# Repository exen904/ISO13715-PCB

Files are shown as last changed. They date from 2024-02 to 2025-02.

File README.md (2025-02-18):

# ISO13715 Macropad

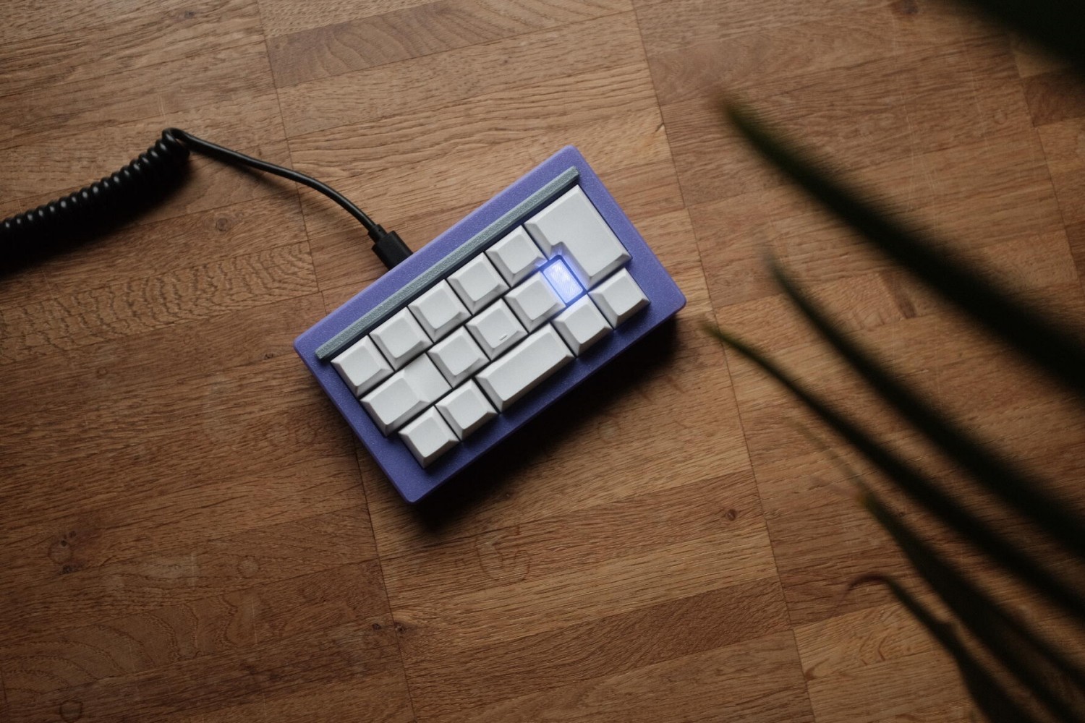
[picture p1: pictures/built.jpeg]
built macropad


Name derives from DIN ISO 13715 ```Kanten mit unbestimmter Gestalt```. Depending on the layout you choose for the bottom row 13/15 keys, 7 where the regular Alpha cluster would be and ISO should be obvious. 

Huge shoutout to PCBway, who sponsored the run of the matte black PCB I used in the build guide. No strings attached here, if you want a matte black PCB, thats the way to go.

## PCB
You can find the Gerber files for ordering your own PCB in the `PCB\production` folder. For service I can absolutely recommend PCBway, who as mentioned above, sponsored my prototype run. Service was great and they deliver quality work, so I can really recommend them.

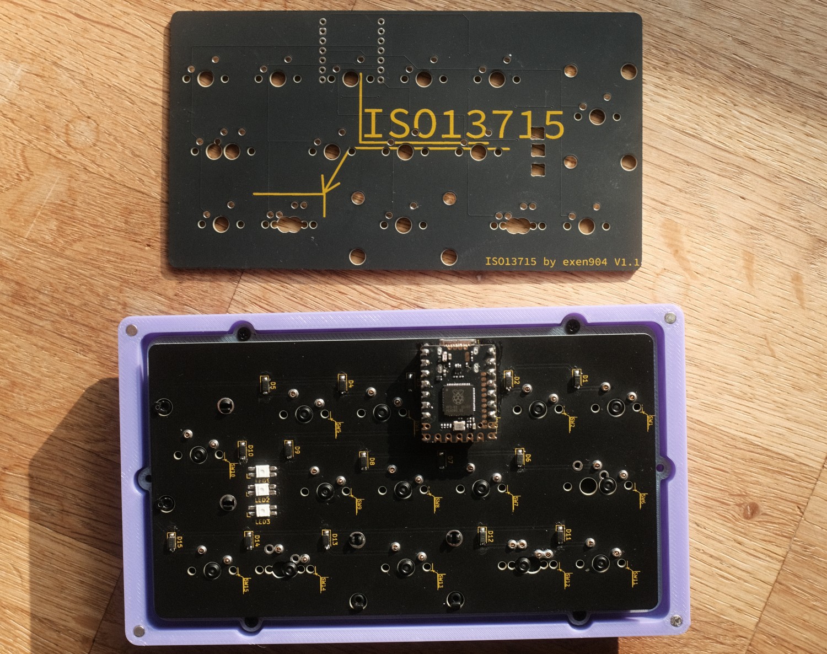
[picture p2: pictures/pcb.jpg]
PCBway PCB


## BOM
- 15x SOD123 Diodes
- 3x SK-6812 MINI-E
- 2x 2U PCB mounted Stabilizers
- 1x MCU of your choice
- 8x 3x3mm magnets for the case
- 4-6x M2x3 heat inserts (4 should be more than fine)
- 4-6x M2x4 screws

For the MCU you have two options. Either XIAO RP2040, or Waveshare RP2040 Zero/0xCB Gemini. Both fit and work, however the pinout is mirrored on either option. I originally designed the PCB for the Xiao, with the MCU facing towards you (not like most split builds with face down MCUs). However, my Proto is built with a RP2040 zero, which has to be flipped on its face. I recommend using IC sockets for the MCU. 

## Case
The current case only supports the HHKB bottom row with 2x 1U keys, the version with the larger blockers is still on my todo. If you cant wait though, feel free to edit the STEP files to your needs. For the diffusor, I chose transparent PETG and for a more unified look, changed the last layer to white. The mounting system of the case itself is inspired from the awesome cases from Bubbleology and uses the same magnets.

For printing, I recommend 0.2mm layer height, anything around 10% infill. How tight the plate works for you also depends on the swichtes you choose, if its too loose you can play around with the XY Hole compensation in your slicer.

## Firmware
I started with a very basic KMK firmware based of POG to test everything, which is still included here in the Repo. However, now I also finished the QMK-VIAL port for the board. I only tested this on a 0xCB Gemini, not on a Xiao RP2040. As the Xiao exposes different pins, those need to be changed before compiling the firmware. I currently dont have one on hand to test, so Im not going to provide untested firmware files. Please adjust here for yourself.

If you are using a Helios/RP2040 Zero, you can use the provided `iso13715_vial_gemini.uf2` in the `Firmware` folder. The VIAL firmware also has bootmagic enabled, so to get into bootloader mode, you just need to hold down the imaginary `ESC` key on the board.

### KLE layout options

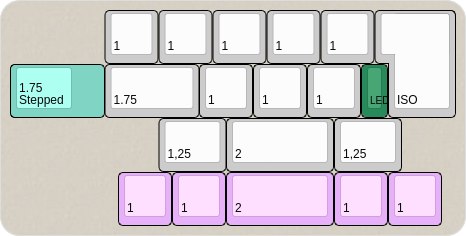
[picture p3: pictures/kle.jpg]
Screenshot of KLE


## Build Guide
[You can find the build guide for the PCB here](https://github.com/exen904/ISO13715-PCB/blob/main/build_guide.md)

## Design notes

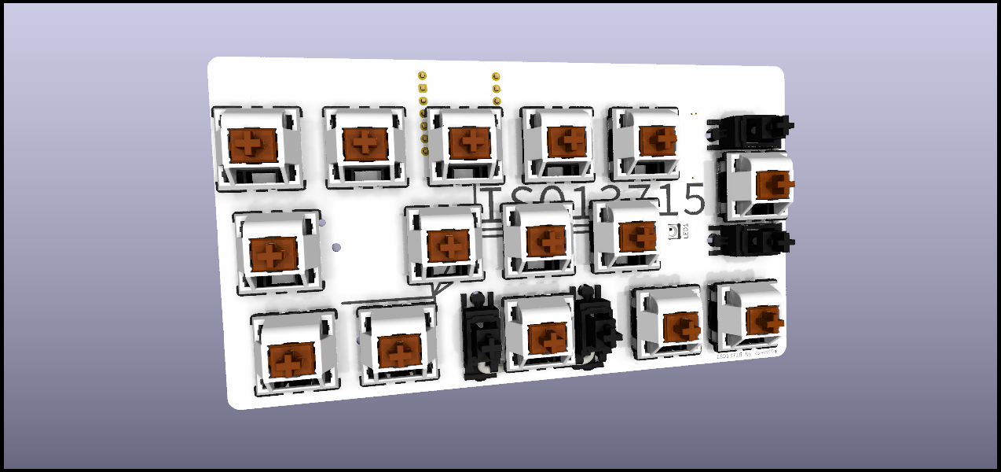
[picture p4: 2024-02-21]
pictures/ISO13715.png

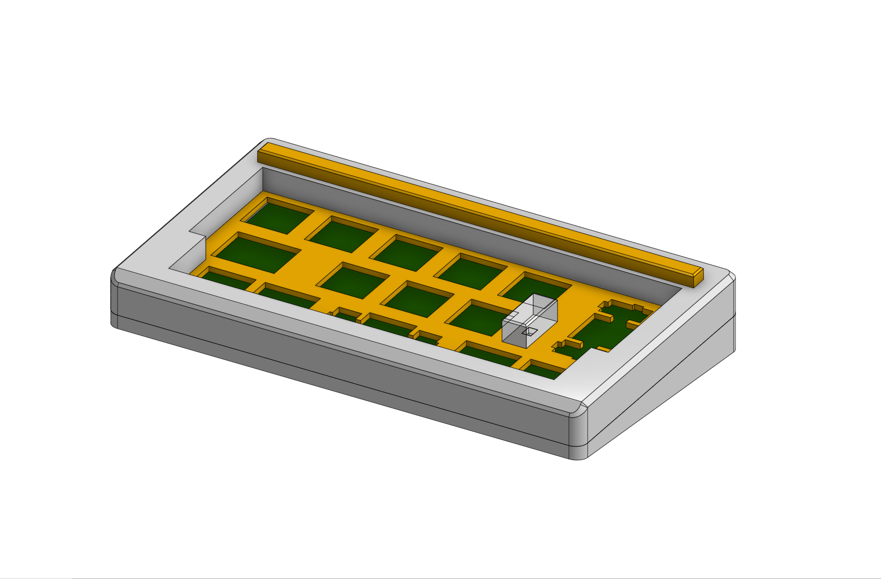
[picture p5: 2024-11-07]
Case/iso13715.png

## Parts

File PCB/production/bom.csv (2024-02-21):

Designator | Footprint | Quantity | Value | LCSC Part #
D1, D10, D11, D12, D13, D14, D15, D2, D3, D4, D5, D6, D7, D8, D9 | D_SOD-123 | 15 | 1N4148W
LED1, LED2, LED3 | LED_6028R | 3 | SK6812MINI-E
SW1, SW6 | SW_MX_1u | 2 | ~
SW10, SW11, SW12, SW13, SW14, SW15, SW2, SW3, SW4, SW5, SW7, SW8, SW9 | SW_MX_1u_3D | 13 | ~
SW17, SW18 | SW_MX_1.25u | 2 | ~
SW20 | SW_MX_1.75u_STP_1.25 | 1 | ~

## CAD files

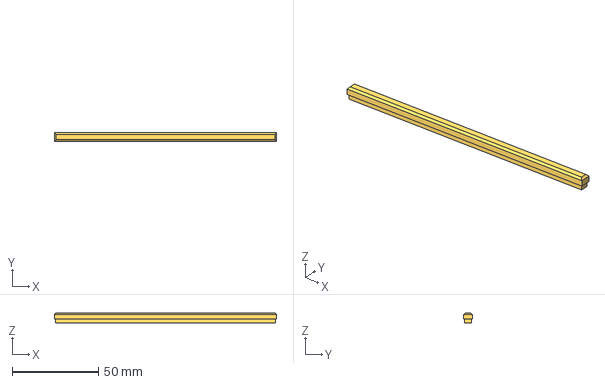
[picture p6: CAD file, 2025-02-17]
Case/STEP/Case - Rail.step
129.0 x 5.03 x 6.10 mm

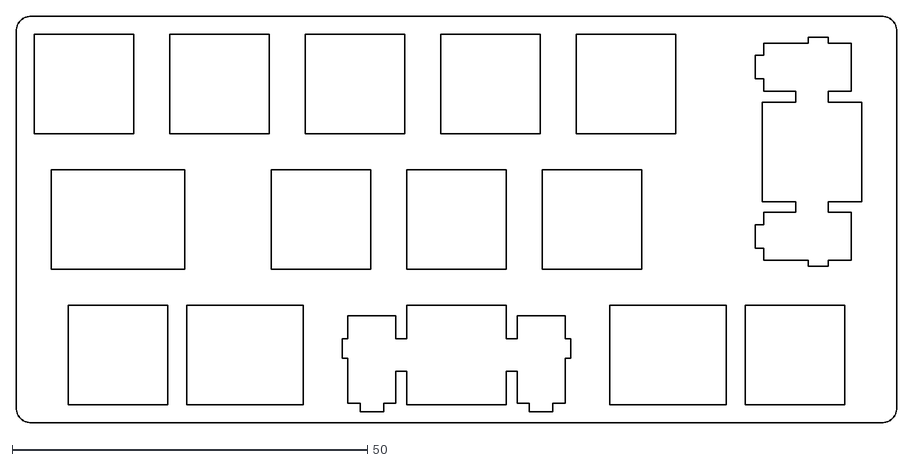
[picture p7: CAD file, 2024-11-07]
Plate/plate_swillkb.dxf
123.8 x 57.2

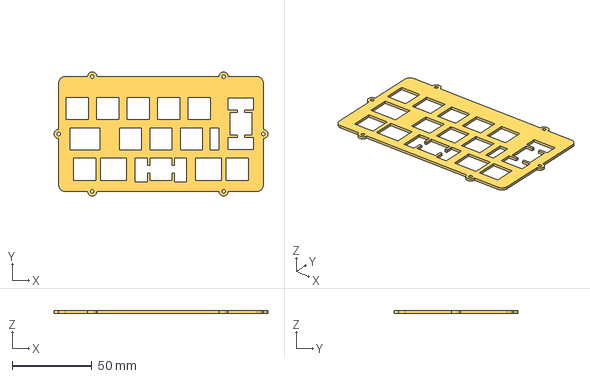
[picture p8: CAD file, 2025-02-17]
Case/STEP/Case - Plate.step
133.8 x 77.6 x 1.60 mm

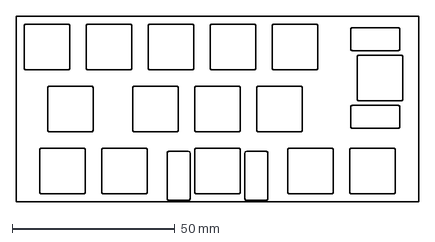
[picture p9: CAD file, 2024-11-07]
Plate/plate-2024-01-22T20_08_51.751Z.dxf
123.8 x 57.1 mm

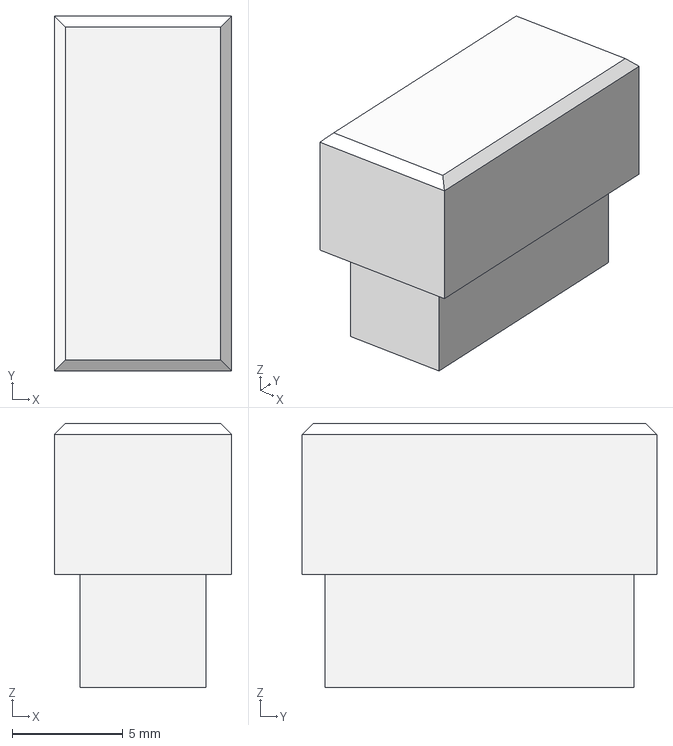
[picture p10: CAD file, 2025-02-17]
Case/STEP/Case - Diffusor.step
8.00 x 16.0 x 11.9 mm

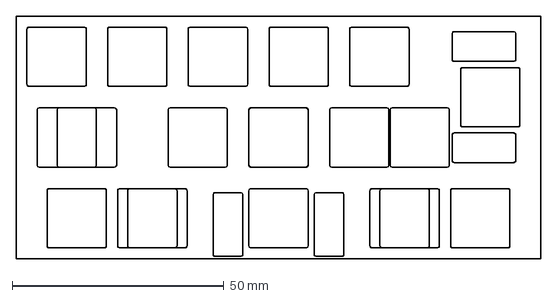
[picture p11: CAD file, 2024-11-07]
Plate/plate-2024-01-23T20_27_40.417Z.dxf
123.8 x 57.1 mm

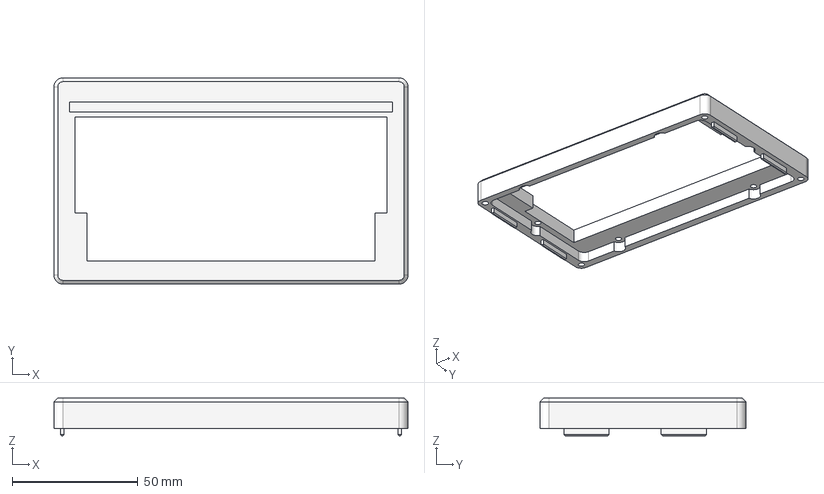
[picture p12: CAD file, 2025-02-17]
Case/STEP/Case - Topcase.step
140.5 x 81.8 x 15.0 mm

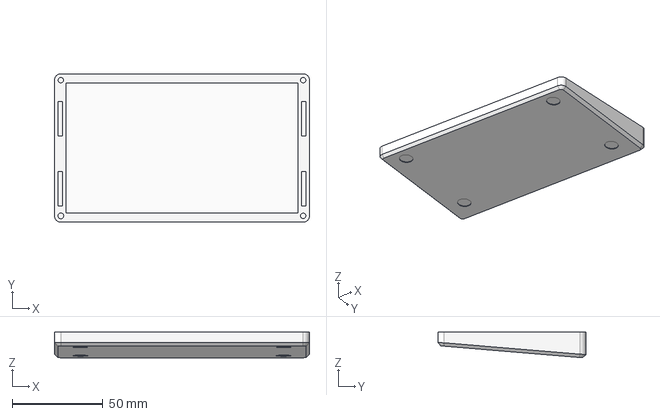
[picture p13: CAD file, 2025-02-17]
Case/STEP/Case - Bottom Case.step
140.5 x 81.8 x 14.1 mm

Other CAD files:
Case/STL/Case - Bottom Case.stl
Case/STL/Case - Diffusor.stl
Case/STL/Case - Plate.stl
Case/STL/Case - Rail.stl
Case/STL/Case - Topcase.stl

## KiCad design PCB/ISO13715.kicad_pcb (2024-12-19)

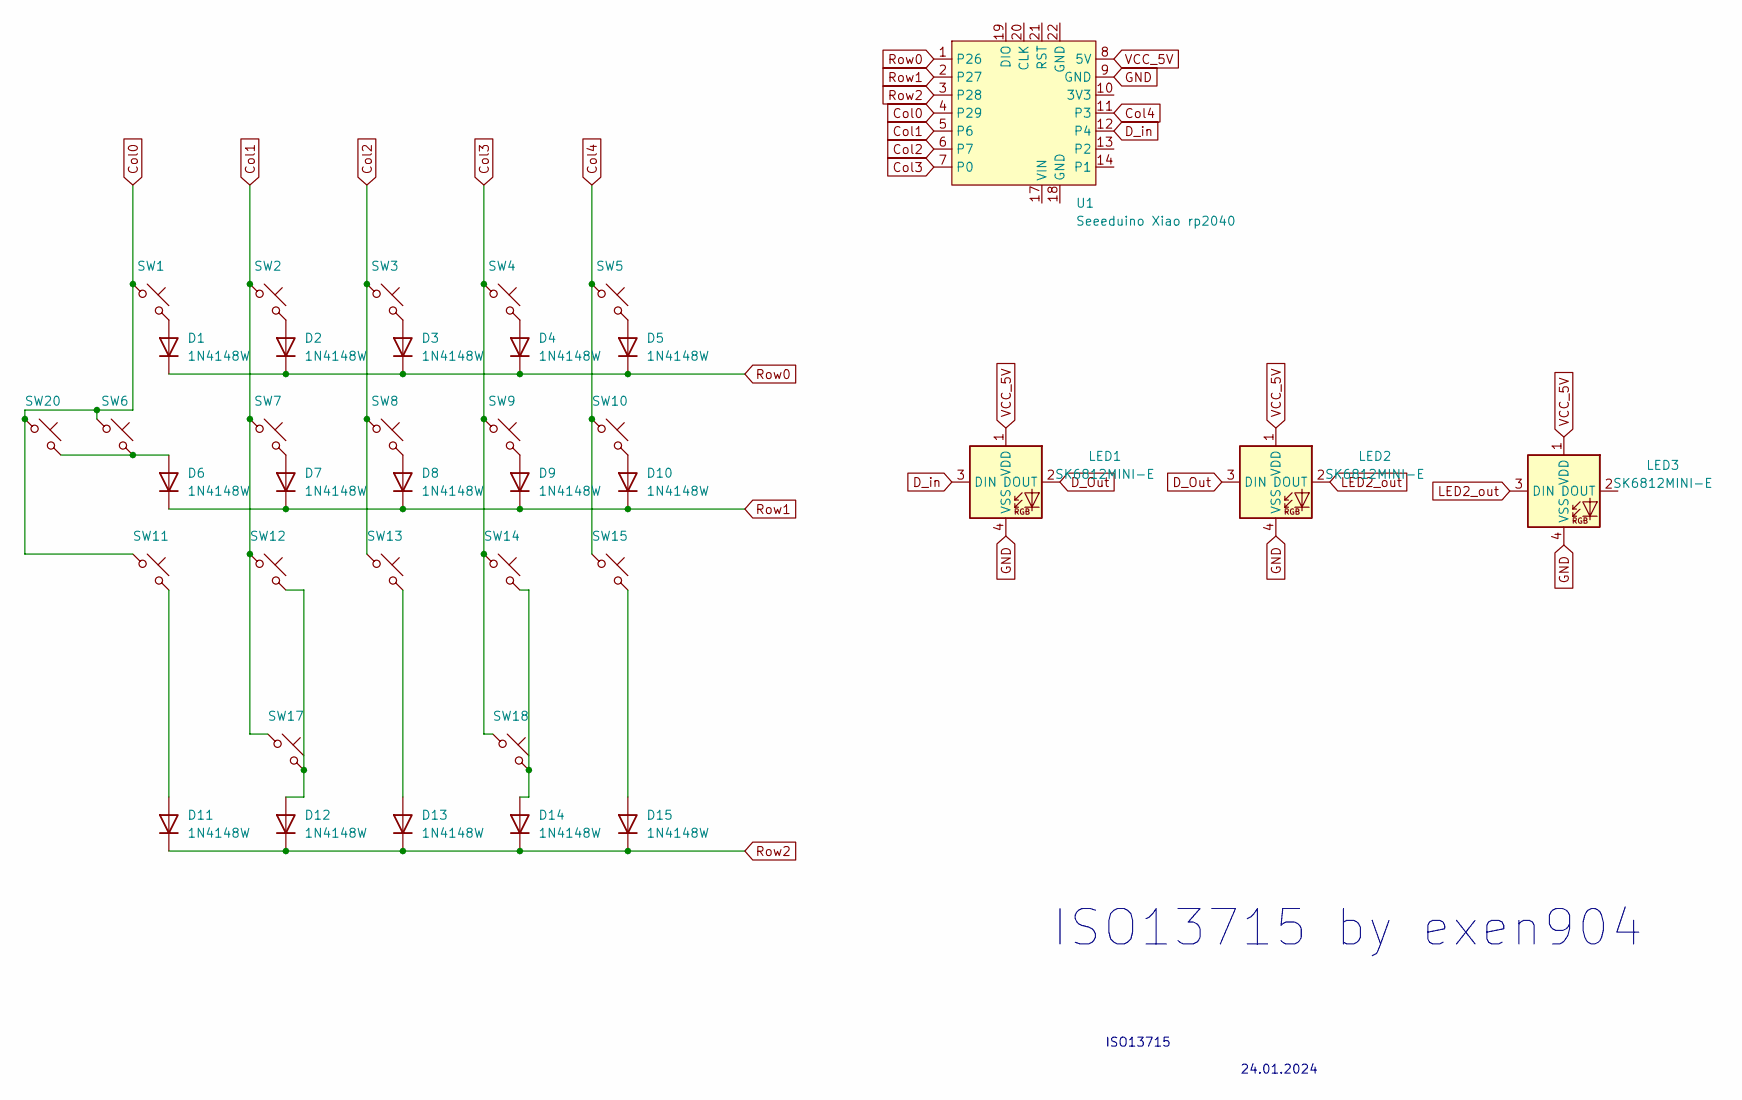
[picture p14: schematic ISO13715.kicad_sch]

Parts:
D1, D2, D3, D4, D5, D6, D7, D8, D9, D10, D11, D12, D13, D14, D15: 1N4148W; D_SOD-123
LED1, LED2, LED3: SK6812MINI-E; LED_6028R
SW1, SW2, SW3, SW4, SW5, SW7, SW8, SW9, SW10, SW11, SW12, SW13, SW14, SW15: SW_MX_1u
SW6, SW20: SW_MX_1.75u
SW17, SW18: SW_MX_1.25u
U1: Seeeduino Xiao rp2040; Xiao_rp2040_AH_Pogo

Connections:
Col0: SW1.1, SW6.1, SW11.1, SW20.1, U1.4 (P29)
Col1: SW2.1, SW7.1, SW12.1, SW17.1, U1.5 (P6)
Col2: SW3.1, SW8.1, SW13.1, U1.6 (P7)
Col3: SW4.1, SW9.1, SW14.1, SW18.1, U1.7 (P0)
Col4: SW5.1, SW10.1, SW15.1, U1.11 (P3)
D_Out: LED1.2 (DOUT), LED2.3 (DIN)
D_in: LED1.3 (DIN), U1.12 (P4)
GND: LED1.4 (VSS), LED2.4 (VSS), LED3.4 (VSS), U1.9 (GND)
LED2_out: LED2.2 (DOUT), LED3.3 (DIN)
unnamed: D1.2 (A), SW1.2
unnamed: D2.2 (A), SW2.2
unnamed: D3.2 (A), SW3.2
unnamed: D4.2 (A), SW4.2
unnamed: D5.2 (A), SW5.2
unnamed: D6.2 (A), SW6.2, SW20.2
unnamed: D7.2 (A), SW7.2
unnamed: D8.2 (A), SW8.2
unnamed: D9.2 (A), SW9.2
unnamed: D10.2 (A), SW10.2
unnamed: D11.2 (A), SW11.2
unnamed: D12.2 (A), SW12.2, SW17.2
unnamed: D13.2 (A), SW13.2
unnamed: D14.2 (A), SW14.2, SW18.2
unnamed: D15.2 (A), SW15.2
Row0: D1.1 (K), D2.1 (K), D3.1 (K), D4.1 (K), D5.1 (K), U1.1 (P26)
Row1: D6.1 (K), D7.1 (K), D8.1 (K), D9.1 (K), D10.1 (K), U1.2 (P27)
Row2: D11.1 (K), D12.1 (K), D13.1 (K), D14.1 (K), D15.1 (K), U1.3 (P28)
VCC_5V: LED1.1 (VDD), LED2.1 (VDD), LED3.1 (VDD), U1.8 (5V)

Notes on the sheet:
ISO13715 by exen904
24.01.2024
ISO13715

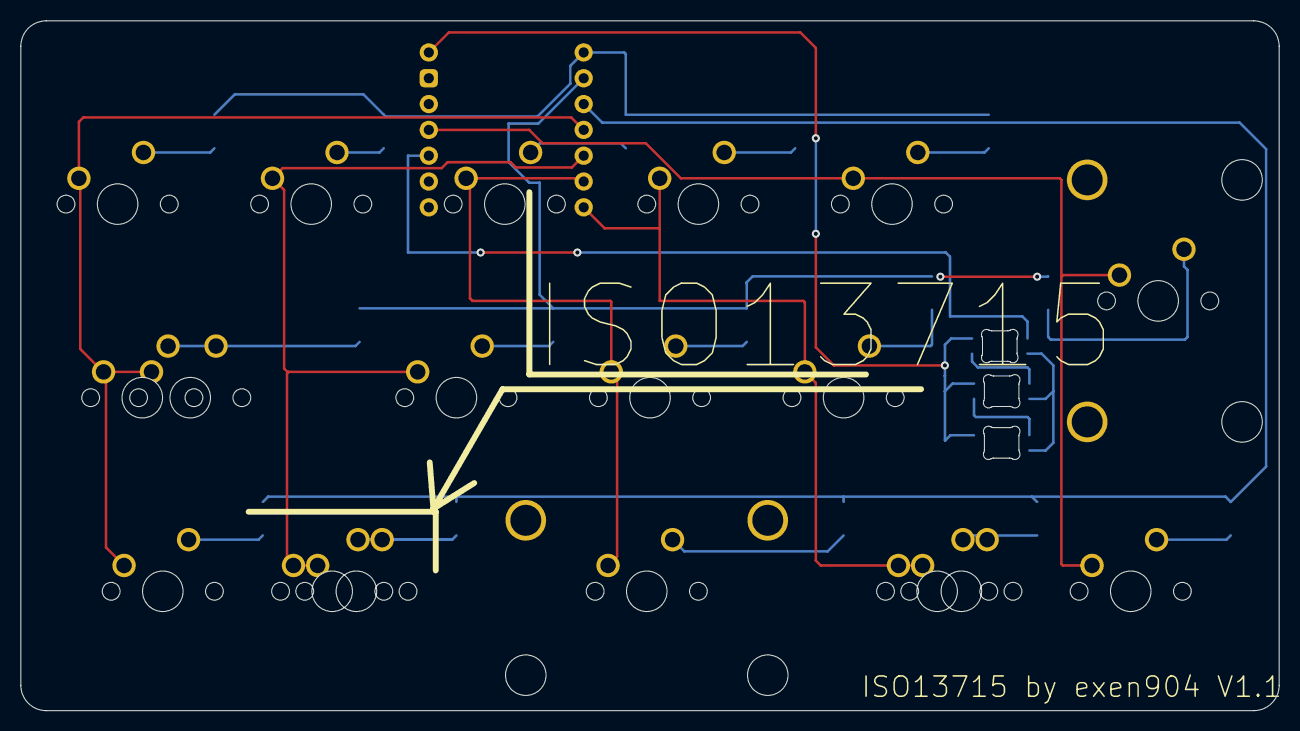
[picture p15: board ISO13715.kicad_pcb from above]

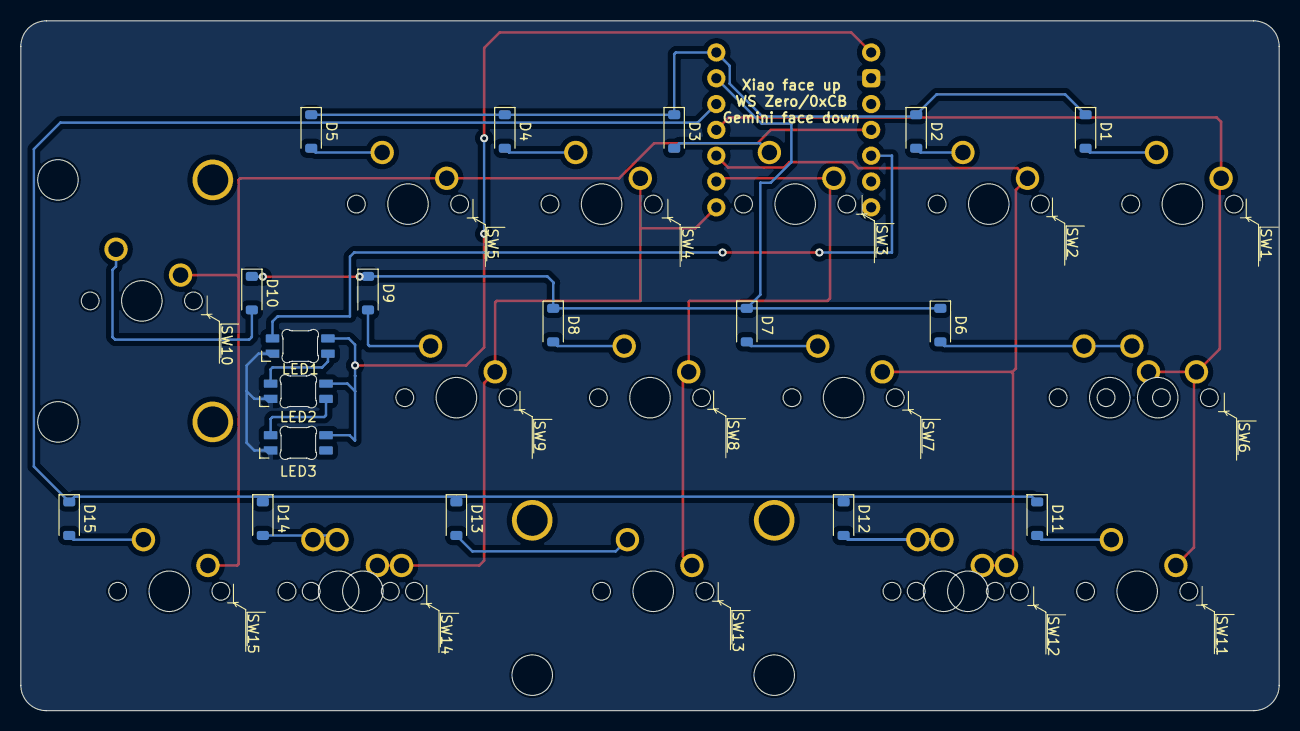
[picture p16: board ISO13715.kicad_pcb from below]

Board: 2 copper layers, 123.8 x 67.9 mm, 37 parts (19 on the bottom side), 28 nets.

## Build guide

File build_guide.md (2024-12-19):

# Build Guide

For this build guide I am using a matte black PCB, which was kindly sponsored by PCBway. Huge shoutout here, I had a great order experience with them and the unique matte black/yellow silkscreen is something I really wanted to try in the past. 
## BOM

- 15x SOD123 Diodes
- 3x SK-6812 MINI-E
- 2x 2U PCB mounted Stabilizers
- 1x MCU of your choice
- 13-15 Switches of your choice
- Keycaps (obviously)

### MCU choice
The PCB design supports two different MCU choices, both based of the RP2040. Depending on which MCU you choose, you have to place it face up or face down. Version 1.1 of the PCB also references this on the silkscreen.

- Option 1: Seeed Xiao RP2040, the MCU footprint is also based on this
	- **face up**
- Option 2: Waveshare RP2040 Zero, 0xCB Gemini (personal preference if youre EU/DE based), 
	- **face down**

## Diodes
The SMD package might be intimidating if you never worked with it before, but I prefer it a lot over the easier looking 1N4148 THT diodes. Its always a pain to get those perfectly straight, clip all the legs, just creates a huge mess and I dont like the clipped solder joints on the other side of the PCB. 

The diodes are directional, you see a mark on one of the pads with a `U-shape` (also towards the MCU). This is your cathode marking which corresponds to a line on top of the diode. To solder these, tin one of the pads first. Place the diode then with tweezers just above that tinned pad, reheat the pad and push the side of the diode on the now heated pad. Before I solder the other side of the diode, I push a little on top of it to make sure its sitting plane on the PCB, while keeping the pad heated. Now solder the other side. Repeat for all of your diodes. You can also tack all of them down on one side first and then solder the other. Just make sure you dont forget any soldering joints. 

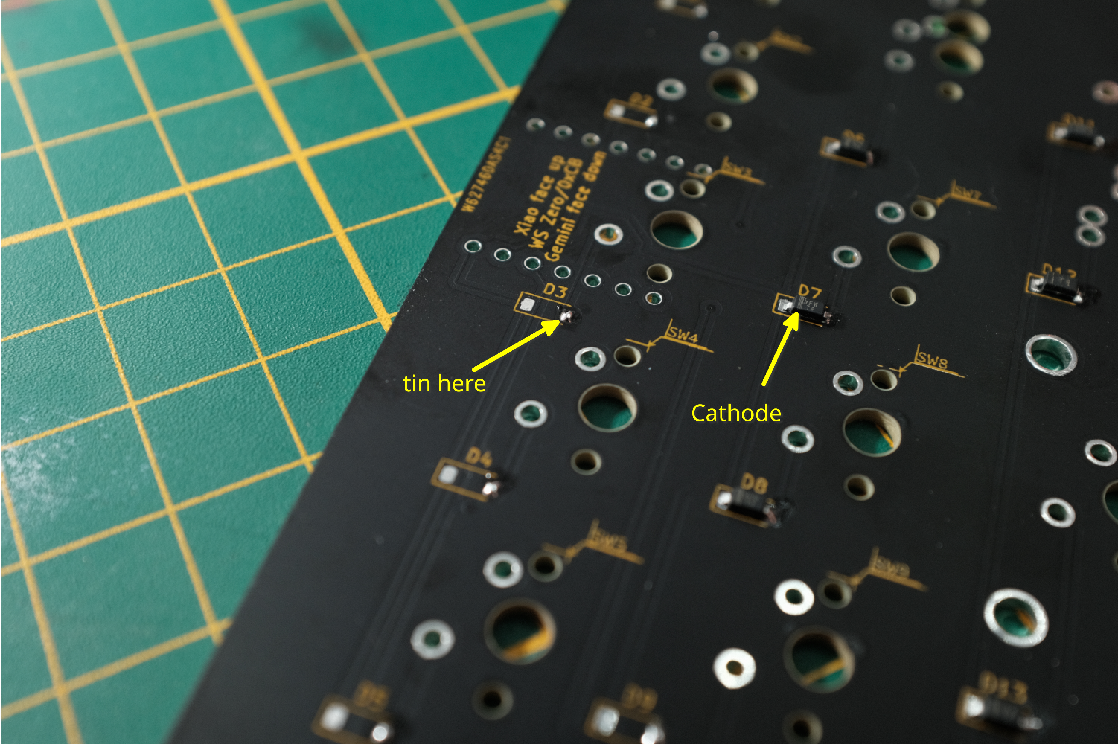
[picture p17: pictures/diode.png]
Diode alignment


## LEDs
The LEDs are a bit more tricky, as they dont like too much heat. For directions, the `GND` pad is marked with an `L-Shape`. Align the feet with the cut here to the L-Shape. For soldering these, I prefer to bump my temperature up a bit and work with as little contact as needed. On the Pinecil, I go up to 400°C for reference. 

Also tin one of the pads, align the LED, re-heat the pad and solder the other joints. If youre not sure that you placed the LED in the correct orientation and the GND leg is covered by solder, you can also look on the front side of the LED. Under the glass pane is a little notch, where your GND is located. If you solder the LEDs in backwards, you create a short and the MCU will go into smoke machine mode after enough time. Dont do this to your MCU. 

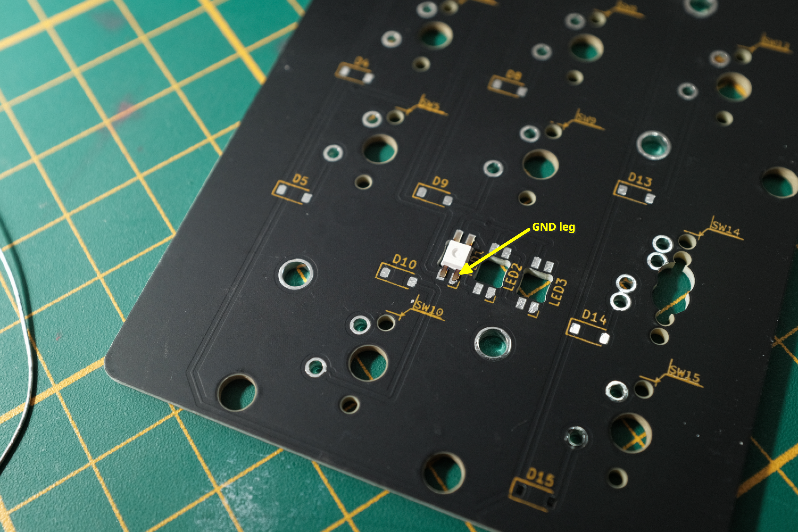
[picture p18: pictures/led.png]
LED alignment


## MCU
I recommend socketing your MCU but you can also work with regular header pins if you want. Just make **really** sure in that case, that your MCU is facing the right way. In this guide, I will refer to socketing the MCU. 

**Before you solder anything here, connect it to your PC and check if you can put your firmware on it. It that works/your MCU turns on, proceed.**

If you are going the Gemini way, you will be left with not connected/needed pins. That is intentional and no issue.

At fist, solder in your socket headers. The so called `IC sockets` work just fine, no need to get the expensive Millmax ones. For soldering these, I fixate it with one pin soldered, check for needed alignment, correct if needed and then solder the remaining pins down. Do this for both sides. 

For pins of your MCU, I personally recommend getting the Millmax pins. Some people use cut of legs of those awful 1N4148 diodes or similar, which are definitely way cheaper, but also the inferior choice. In the past I had connection issues with them, as they are much slimmer in diameter and maybe not contact your socket headers correctly. They also bend if you just look at them, which can make removing/inserting the MCU in the headers more difficult. 

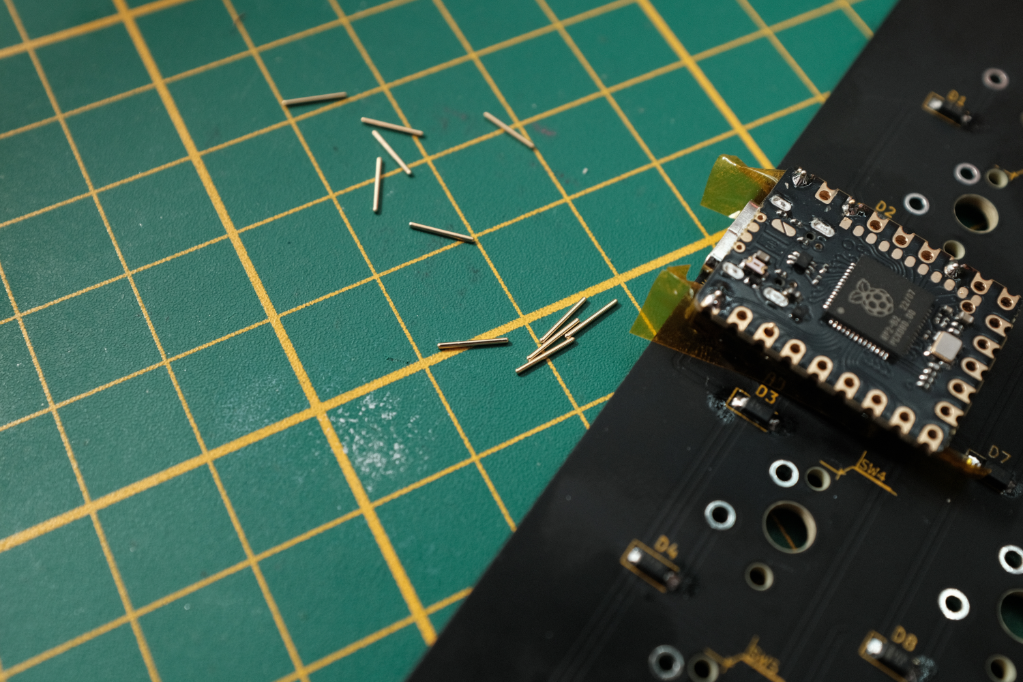
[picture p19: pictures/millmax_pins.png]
Millmax Pins


For soldering the pins in, I place them in the socket headers and the MCU on top. To prevent solder from permanently fuse your pins and sockets together, cover the socket headers first with a layer of kapton tape. I then use a sewing needle to pierce the kapton in preparation for the Millmax pins. I recommend alternating left/right while soldering the pins to your MCU for a bit better thermal management of your MCU PCB. I never really had any issues with RP2040 based MCUs here, but I like to make sure. 

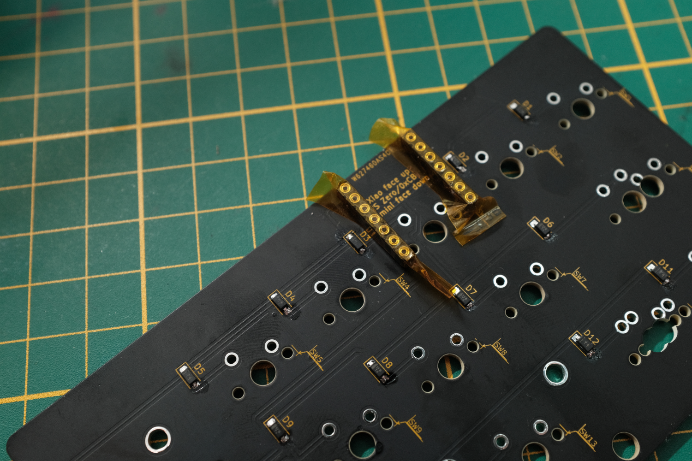
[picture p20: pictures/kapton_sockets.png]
Sockets with Kapton

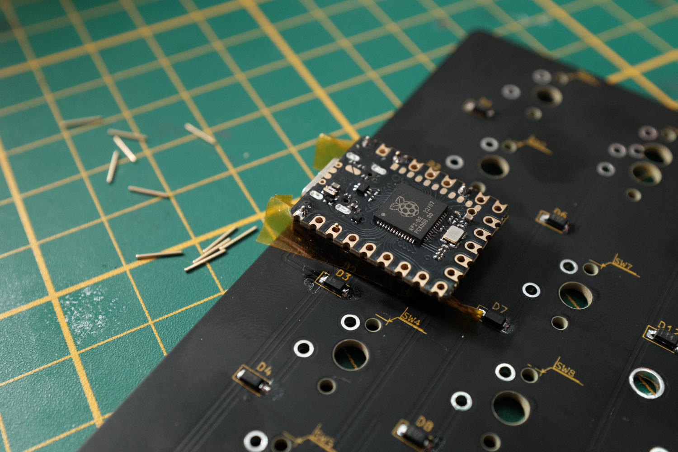
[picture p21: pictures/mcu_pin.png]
MCU soldering


After you soldered your pins, remove the MCU, peel off the tape and you can start soldering your switches. 

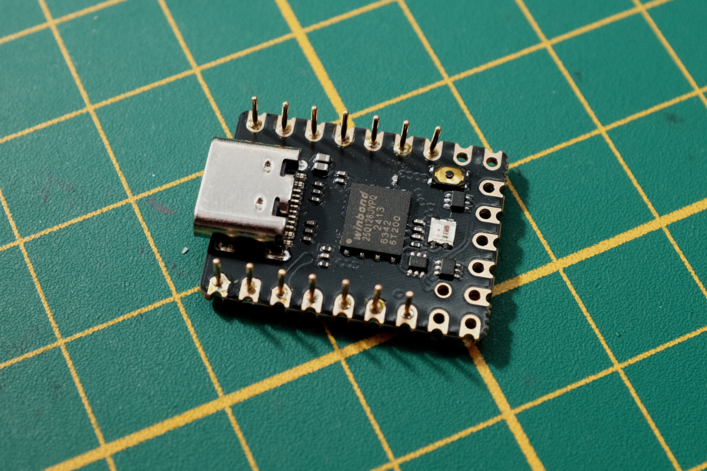
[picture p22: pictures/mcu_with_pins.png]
MCU with pins


## Switches, Stabilizers, Keycaps
**Remember to first print the plate from the case before you solder Switches!** The PCB is Millmax Socket compatible by the way, tested with mine.

Solder your switches in the positions for your wanted layout, please check with keycaps if you are not sure what to use. 

Install stabilizers and keycaps, I will not explain this one.

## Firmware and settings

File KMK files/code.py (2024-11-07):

# Main Keyboard Configuration - v1.0.0
import board
import pog
# check if we just want to run the coord_mappping Assistant
if pog.coordMappingAssistant:
    from coordmaphelper import CoordMapKeyboard
    if __name__ == '__main__':
        CoordMapKeyboard().go()
    print("Exiting Coord Mapping Assistant Because of an error")
else:
    from kb import POGKeyboard
    # set the required features for you keyboard and keymap
    # add custom ones in the kb.py

    keyboard = POGKeyboard(features=pog.kbFeatures)

    # manage settings for our modules and extensions here
    keyboard.tapdance.tap_time = 200

    # Keymap
    import keymap
    keyboard.keymap = keymap.keymap

    # Encoder Keymap if available
    if pog.hasEncoders:
        keyboard.encoder_handler.map = keymap.encoderKeymap

    # Execute the keyboard loop
    if __name__ == '__main__':
        keyboard.go()

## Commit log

2024-02-21 update to pcb
    [ISO13715.kicad_pcb, ISO13715.kicad_sch]
2024-02-21 changed GND to plane
    [ISO13715.kicad_pcb, bom.csv, designators.csv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]
2024-11-07 updated PCB and readme
    [ISO13715.kicad_pcb, bom.csv, designators.csv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]
2024-11-07 added case
    [Case - Bottom Case.step, Case - Bottom Case.stl, Case - Diffusor.step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]
2024-12-19 created build guide
    [ISO13715.kicad_pcb]
2025-02-17 updated case files to new magnet version
    [Case - Bottom Case.step, Case - Bottom Case.stl, Case - Diffusor.step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]
